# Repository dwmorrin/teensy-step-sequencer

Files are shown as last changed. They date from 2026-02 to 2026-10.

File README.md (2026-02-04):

# Teensy Step Sequencer

This project implements a hardware-based step sequencer using the Teensy 4.1 microcontroller. It utilizes the Teensy's onboard USB Host capabilities to accept input from standard USB keyboards, alongside a custom 32-switch diode matrix for tactile control.

## Gallery

### Version 1 first build
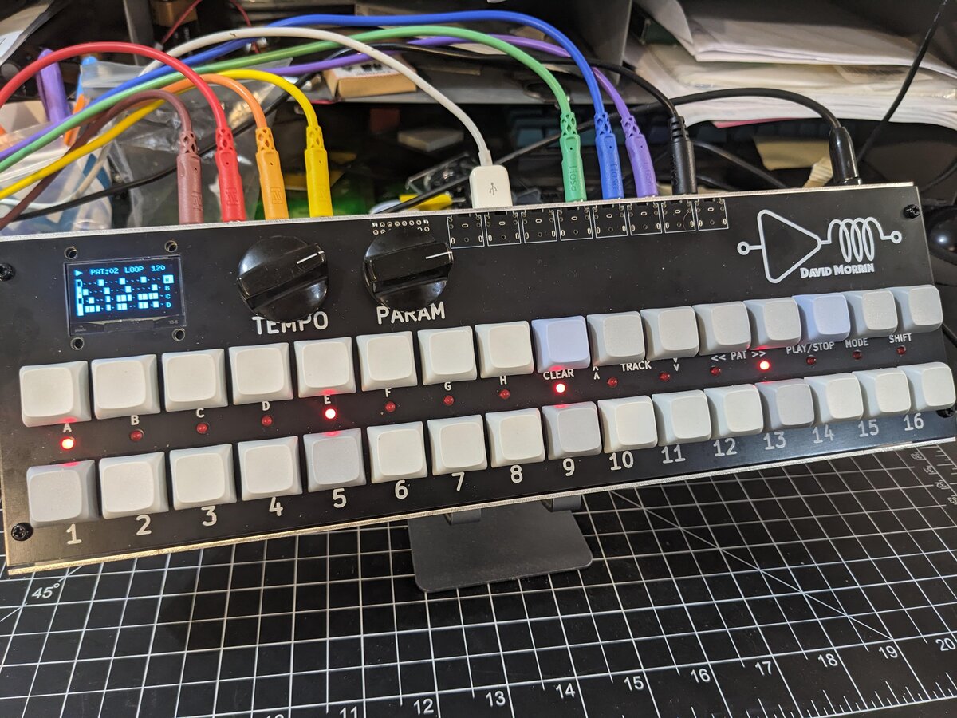
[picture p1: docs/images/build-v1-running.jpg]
Version 1 first build


### Prototype

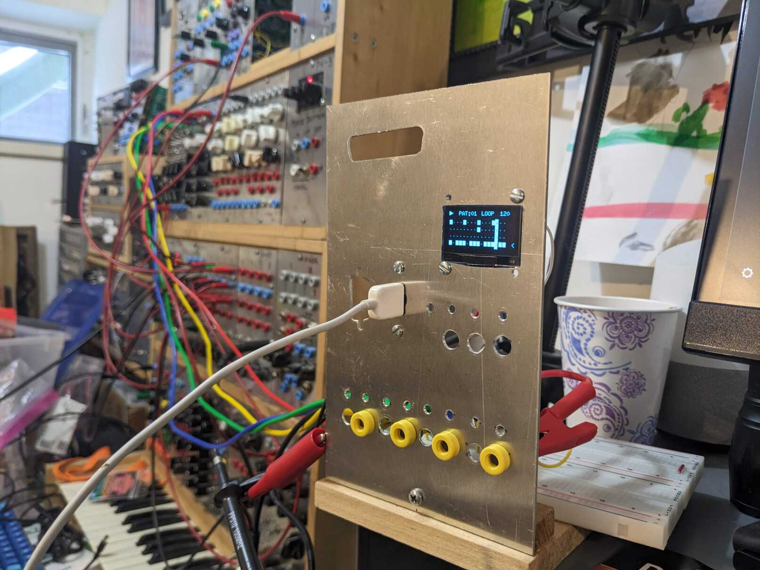
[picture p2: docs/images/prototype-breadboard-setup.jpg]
Breadboard Setup


### Hardware Renders

| Main Board | Switchplate |
| :---: | :---: |
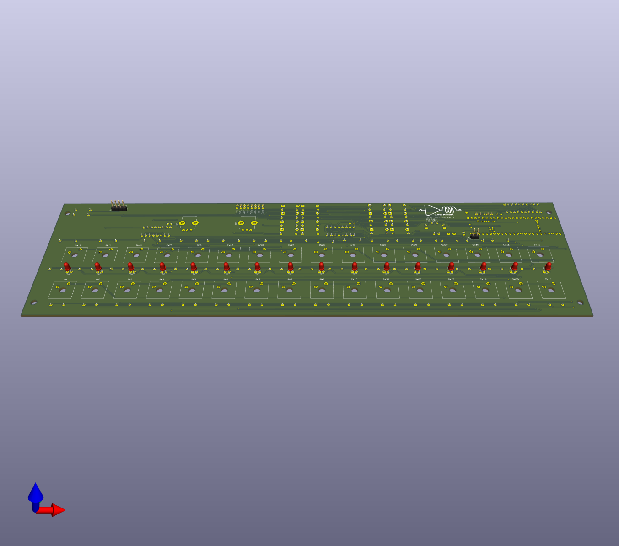
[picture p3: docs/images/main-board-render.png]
Main Board Render
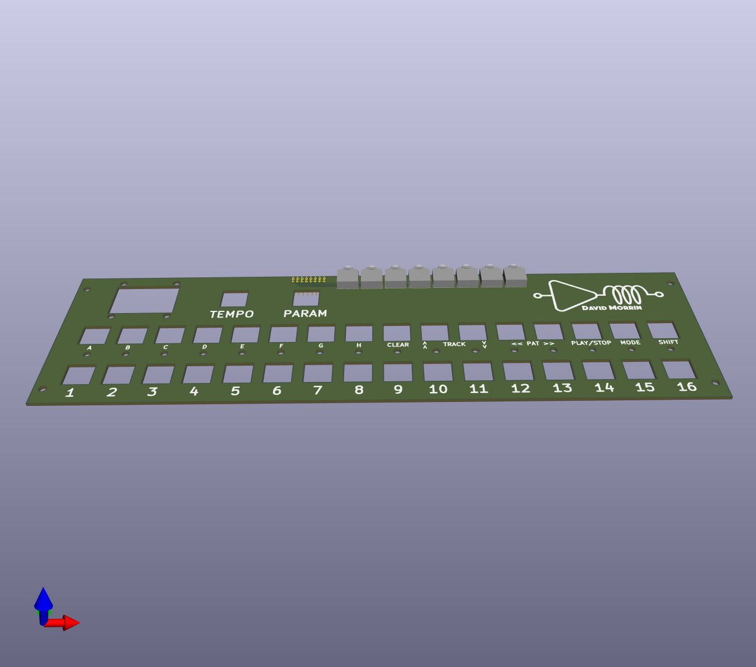
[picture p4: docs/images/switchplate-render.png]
Switchplate Render
|  |  |

## System Overview

The application is designed as a standalone, embedded instrument. It functions as an **8-track** step sequencer with support for **96 PPQN high-resolution timing**, pattern chaining (Song Mode), **per-track swing**, real-time performance triggers, and visual feedback via an I2C OLED display with scrolling track views.

### Hardware Dependencies

- **Microcontroller:** Teensy 4.1 (Selected for native USB Host and RAM capacity).
- **Display:** - 1.3" SH1106 OLED (I2C) for the graphical interface.
  - 16x LEDs driven by 74HC595 Shift Registers for step visualization.
- **Input:** - Standard USB HID Keyboard (via USB Host).
  - 4x8 Diode Matrix Keyboard (32 switches).
  - 2x Analog Potentiometers (Tempo and Parameter control).
- **Output:** **8x** 5V Logic Triggers (GPIO).

## Software Architecture

The codebase adopts a modular architecture separating data, presentation, and hardware control. The source code located in `src/` is organized into the following domains:

- **Model** (`src/Model/`)
  This directory contains the core logic and data structures. It serves as the single source of truth for the application, managing the Pattern Pool, the Playlist (Song Mode), Swing parameters, and the Undo buffer. The Model is decoupled from hardware; it does not know if it is being driven by a clock or edited by a keyboard.

- **View** (`src/View/`)
  This directory handles all visual output.
  - `DisplayManager`: Observes the Model and renders the interface (Grid, Transport, Headers) to the OLED. It handles **viewport scrolling** to display 8 tracks on a 4-track height screen.
  - `StepLeds`: Manages the 16-step LED array via SPI shift registers.
    The view layer includes internal throttling logic to maintain a consistent frame rate without blocking the audio/timing threads.

- **Controller** (`src/Controller/`)
  This directory manages user input and state routing. The `UIManager` aggregates inputs from multiple hardware sources:
  - **USB Keyboard:** Handled via the Teensy USBHost_t36 library.
  - **Matrix:** Handled by `KeyMatrix`, a custom driver for scanning the 4x8 diode array.
  - **Analog:** Handled by `AnalogInput`, which provides hysteresis and signal smoothing for potentiometers.

  Inputs are translated into abstract `InputCommands` (e.g., `CMD_TRANSPORT_TOGGLE`), decoupling the physical control method from the internal application logic.

- **Engine** (`src/Engine/`)
  This directory handles real-time operations.
  - `ClockEngine`: A **96 PPQN** (Pulses Per Quarter Note) interrupt-driven engine. It calculates micro-timing for **Swing** and groove effects, offering 24 "ticks" per 16th-note step.
  - `OutputDriver`: Abstraction layer for the physical hardware. It converts track bitmasks into GPIO signals using high-precision interrupt timers.

- **Configuration** (`src/Config.h`)
  A global header file defining build-time constraints, including track count, pattern limits, pin mappings, and signal polarity.

## Expansion Guidelines

The system is designed to be extensible. Developers looking to expand functionality should consider the following architectural patterns:

### Persistence (SD Card Storage)

Current pattern data is stored in volatile RAM and is lost upon power cycle. The Teensy 4.1 includes a native micro-SD card slot. Future development should implement a `PersistenceManager` class. This component should:

1.  Serialize the `SequencerModel` data structures (Pattern Pool and Playlist) into a binary or JSON format.
2.  Write to the SD card using the standard Arduino SD library.
3.  Interface with the `UIManager` to allow loading and saving of projects.

## Timing Calculation

The system timing is based on a standard 4/4 time signature where a "beat" represents a quarter note. 

The engine runs at **96 PPQN** resolution. The interval $T$ (milliseconds per tick) is calculated as:

$$T = \frac{60,000}{BPM \times 96}$$

For a standard trigger pulse width of 15ms, the system manages overlapping triggers via a pulse-counter in the interrupt service routine.

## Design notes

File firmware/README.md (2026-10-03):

# 8-Track Performance Sequencer (Firmware v1.0.0)

A interrupt-driven step sequencer for Teensy 4.1.

## Features

- **8-Track Polyphony:** 8 independent trigger outputs.
- **96 PPQN Timing Engine:** High-resolution jitter-free timing based on hardware interrupts.
- **Groove Engine:** Per-track Swing (0-100%) with visual grid feedback.
- **Performance Quantization:** Launch patterns synced to 1 Bar, 1/4 Note, 1/8 Note, or Instant.
- **Song Mode:** Chained pattern playback with insert/delete editing.
- **Persistent Storage:** Save and load entire sequencer state (BPM, Patterns, Playlist) to the Teensy's built-in microSD card in JSON format.
- **Scrolling Interface:** 128x64 OLED UI with auto-scrolling track view and "Gutter" labels.

## Controls

### Global & Transport

| Button | Function | Shift Function |
| :--- | :--- | :--- |
| **PLAY** | Play / Stop | **Quantize Menu** (Set Launch Mode) |
| **MODE** | Toggle Song / Loop Mode | Toggle Edit / Perform Mode |
| **BPM**  | Enter BPM Menu | - |
| **UNDO** | - | **Undo Last Action** (Shift + H) |

### Navigation & Selection

| Button | Function | Shift Function |
| :--- | :--- | :--- |
| **A** | Select Track 1 | **Save State to SD** |
| **B** | Select Track 2 | **Load State from SD** |
| **C - H** | Select Active Track (3 - 8) | - |
| **< / >** | Previous / Next Pattern | - |
| **^ / v** | Previous / Next Track (Scrolls View) | - |

### Editing (Step Edit Mode)

| Control | Action |
| :--- | :--- |
| **Steps 1-16** | Toggle Step ON/OFF |
| **Param Pot** | _Unused in Loop Mode_ |
| **Shift + Param** | **Set Swing %** for Active Track |

### Performance (Perform Mode)

| Control | Action |
| :--- | :--- |
| **Steps 1-8** | Manual Trigger / Finger Drumming |

### Song Mode (Playlist)

| Control | Action | Shift Action |
| :--- | :--- | :--- |
| **Param Pot**  | Select Pattern for current slot | - |
| **< / >** | Move Cursor / Scroll Playlist | Insert Slot Before/After |
| **Clear** | Delete Current Slot | - |
| **Steps 1-16** | Quick Select Pattern Bank | Select Bank 1-4 |

## Architecture

- **Model:** `SequencerModel` holds the state (Patterns, Playlist, Swing). It is decoupled from the engine.
- **Storage:** `StorageManager` serializes the model to/from JSON and interfaces with the built-in SD card.
- **Engine:** `ClockEngine` runs at **2kHz** (0.5ms interval), accumulating time to drive a **96 PPQN** virtual clock. It handles swing delays and trigger pulse widths.
- **Controller:** `UIManager` maps a 4x8 Matrix and Analog Inputs to Commands.
- **View:** `DisplayManager` renders the state to an SSD1306 OLED, handling scrolling offsets and overlays.

## Hardware Map

- **MicroSD:** Teensy 4.1 Built-in SDIO
- **Outputs 1-8:** Pins 25-32
- **Tempo Pot:** Pin 14
- **Param Pot:** Pin 15
- **Matrix Rows:** 36, 34, 38, 40 (Active Low)
- **Matrix Cols:** 20, 17, 16, 41, 39, 37, 35, 33 (Input Pullup)

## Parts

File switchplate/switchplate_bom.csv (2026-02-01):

Reference | Qty | Value | DNP | Exclude from BOM | Exclude from Board | Footprint | Datasheet | MPN
J1,J2,J3,J4,J5,J6,J7,J8 | 8 | AudioJack2 |  |  |  | Connector_Audio:Jack_3.5mm_CUI_SJ1-3523N_Horizontal | https://www.mouser.com/datasheet/3/6118/1/sj1_352xn.pdf | SJ1-3523N
J9 | 1 | Conn_02x08_Odd_Even |  |  |  | Connector_PinHeader_2.54mm:PinHeader_2x08_P2.54mm_Vertical | https://suddendocs.samtec.com/productspecs/tsw-sxx.pdf | TSW-108-14-T-D

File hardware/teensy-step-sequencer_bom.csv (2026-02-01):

Reference | Qty | Value | DNP | Exclude from BOM | Exclude from Board | Footprint | Datasheet
C1 | 1 | 100u |  |  |  | Capacitor_THT:CP_Radial_D5.0mm_P2.50mm | ~
C2,C3,C4 | 3 | 100n |  |  |  | Capacitor_THT:C_Disc_D5.0mm_W2.5mm_P2.50mm | ~
D1,D2,D3,D4,D5,D6,D7,D8,D9,D10,D11,D12,D13,D14,D15,D16,D19,D20 | 18 | LED |  |  |  | LED_THT:LED_D3.0mm | ~
D17,D18,D21,D22,D23,D24,D25,D26,D27,D28,D29,D30,D31,D32,D33,D34 | 16 | 1N5817 |  |  |  | Diode_THT:D_DO-15_P10.16mm_Horizontal | http://www.vishay.com/docs/88525/1n5817.pdf
D35,D36,D37,D38,D39,D40,D41,D42,D43,D44,D45,D46,D47,D48,D49,D50,D51,D52,D53,D54,D55,D56,D57,D58,D59,D60,D61,D62,D63,D64,D65,D66 | 32 | 1N4148 |  |  |  | Diode_THT:D_DO-35_SOD27_P7.62mm_Horizontal | ~
J1 | 1 | SH1106 Screen |  |  |  | Connector_PinHeader_2.54mm:PinHeader_1x04_P2.54mm_Vertical | ~
J2 | 1 | Output |  |  |  | Connector_PinHeader_2.54mm:PinHeader_2x08_P2.54mm_Vertical | ~
J3 | 1 | USB_HOST |  |  |  | Connector_PinHeader_2.54mm:PinHeader_1x05_P2.54mm_Vertical | ~
J4 | 1 | EXT_PWR |  |  |  | Connector_PinHeader_2.54mm:PinHeader_1x02_P2.54mm_Vertical | ~
R1,R2 | 2 | 4k7 |  |  |  | Resistor_THT:R_Axial_DIN0207_L6.3mm_D2.5mm_P10.16mm_Horizontal | ~
R3,R4,R5,R6,R7,R8,R9,R10,R11,R12,R13,R14,R15,R16,R17,R18,R20,R22,R23,R25,R26,R29,R30,R31,R32 | 25 | 330 |  |  |  | Resistor_THT:R_Axial_DIN0207_L6.3mm_D2.5mm_P10.16mm_Horizontal | ~
R19,R21,R24,R27,R28,R33,R34,R35,R36 | 9 | 1k |  |  |  | Resistor_THT:R_Axial_DIN0207_L6.3mm_D2.5mm_P10.16mm_Horizontal | ~
RV1,RV2 | 2 | 100k |  |  |  | Potentiometer_THT:Potentiometer_Bourns_PTV09A-1_Single_Vertical | ~
SW1,SW2,SW3,SW4,SW5,SW6,SW7,SW8,SW9,SW10,SW11,SW12,SW13,SW14,SW15,SW16,SW17,SW18,SW19,SW20,SW21,SW22,SW23,SW24,SW25,SW26,SW27,SW28,SW29,SW30,SW31,SW32 | 32 | CherryMX |  |  |  | CherryMX:CherryMX_1.00u
TP1 | 1 | 5V |  |  |  | TestPoint:TestPoint_Keystone_5000-5004_Miniature | ~
TP2 | 1 | 3V3 |  |  |  | TestPoint:TestPoint_Keystone_5000-5004_Miniature | ~
TP3 | 1 | GND |  |  |  | TestPoint:TestPoint_Keystone_5000-5004_Miniature | ~
U1 | 1 | Teensy4.1 |  |  |  | teensy:Teensy41
U2,U3 | 2 | 74HC595 |  |  |  | Package_DIP:DIP-16_W7.62mm | http://www.ti.com/lit/ds/symlink/sn74hc595.pdf
U4 | 1 | 74HCT245 |  |  |  | Package_DIP:DIP-20_W7.62mm | http://www.ti.com/lit/gpn/sn74HC245

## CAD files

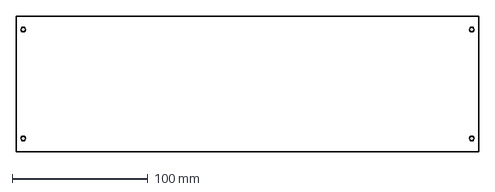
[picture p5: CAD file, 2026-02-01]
mechanical/board_edge.dxf
340.0 x 100.0 mm

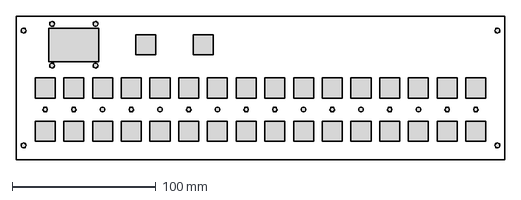
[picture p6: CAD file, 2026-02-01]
mechanical/component_guides.dxf
340.0 x 100.0 mm

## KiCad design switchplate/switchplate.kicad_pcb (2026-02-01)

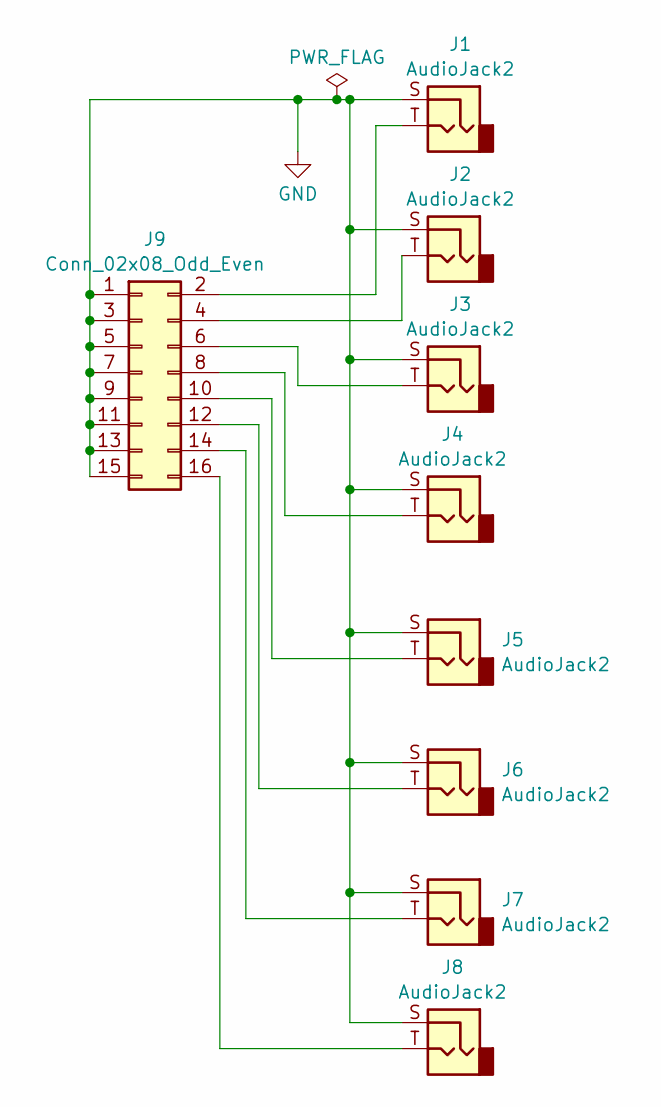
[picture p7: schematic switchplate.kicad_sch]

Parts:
J1, J2, J3, J4, J5, J6, J7, J8: AudioJack2; Jack_3.5mm_CUI_SJ1-3523N_Horizontal; MPN SJ1-3523N
J9: Conn_02x08_Odd_Even; PinHeader_2x08_P2.54mm_Vertical; MPN TSW-108-14-T-D

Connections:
GND: J1.S, J2.S, J3.S, J4.S, J5.S, J6.S, J7.S, J8.S, J9.1, J9.3, J9.5, J9.7, J9.9, J9.11, J9.13, J9.15
unnamed: J1.T, J9.2
unnamed: J2.T, J9.4
unnamed: J3.T, J9.6
unnamed: J4.T, J9.8
unnamed: J5.T, J9.10
unnamed: J6.T, J9.12
unnamed: J7.T, J9.14
unnamed: J8.T, J9.16

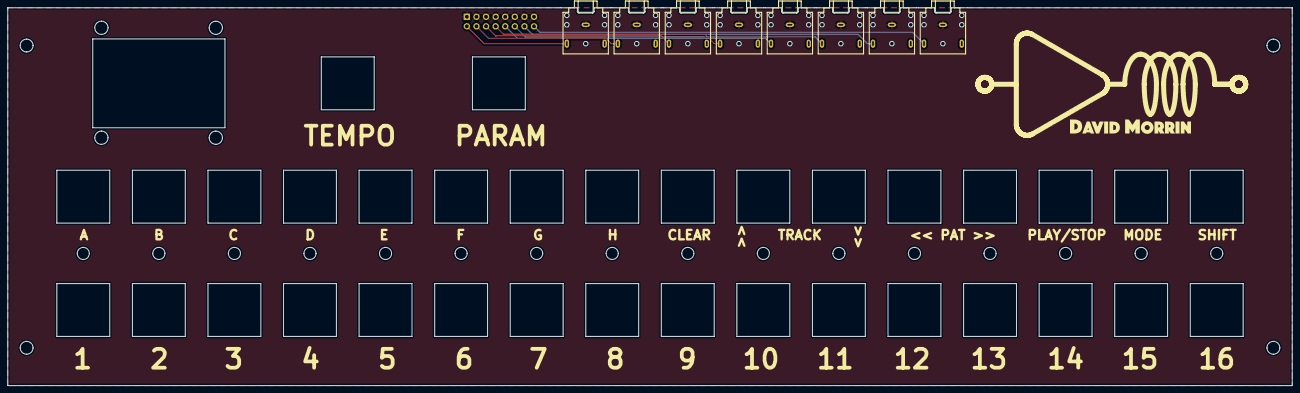
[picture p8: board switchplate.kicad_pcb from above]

Board: 2 copper layers, 340.0 x 100.0 mm, 9 parts (1 on the bottom side), 9 nets.

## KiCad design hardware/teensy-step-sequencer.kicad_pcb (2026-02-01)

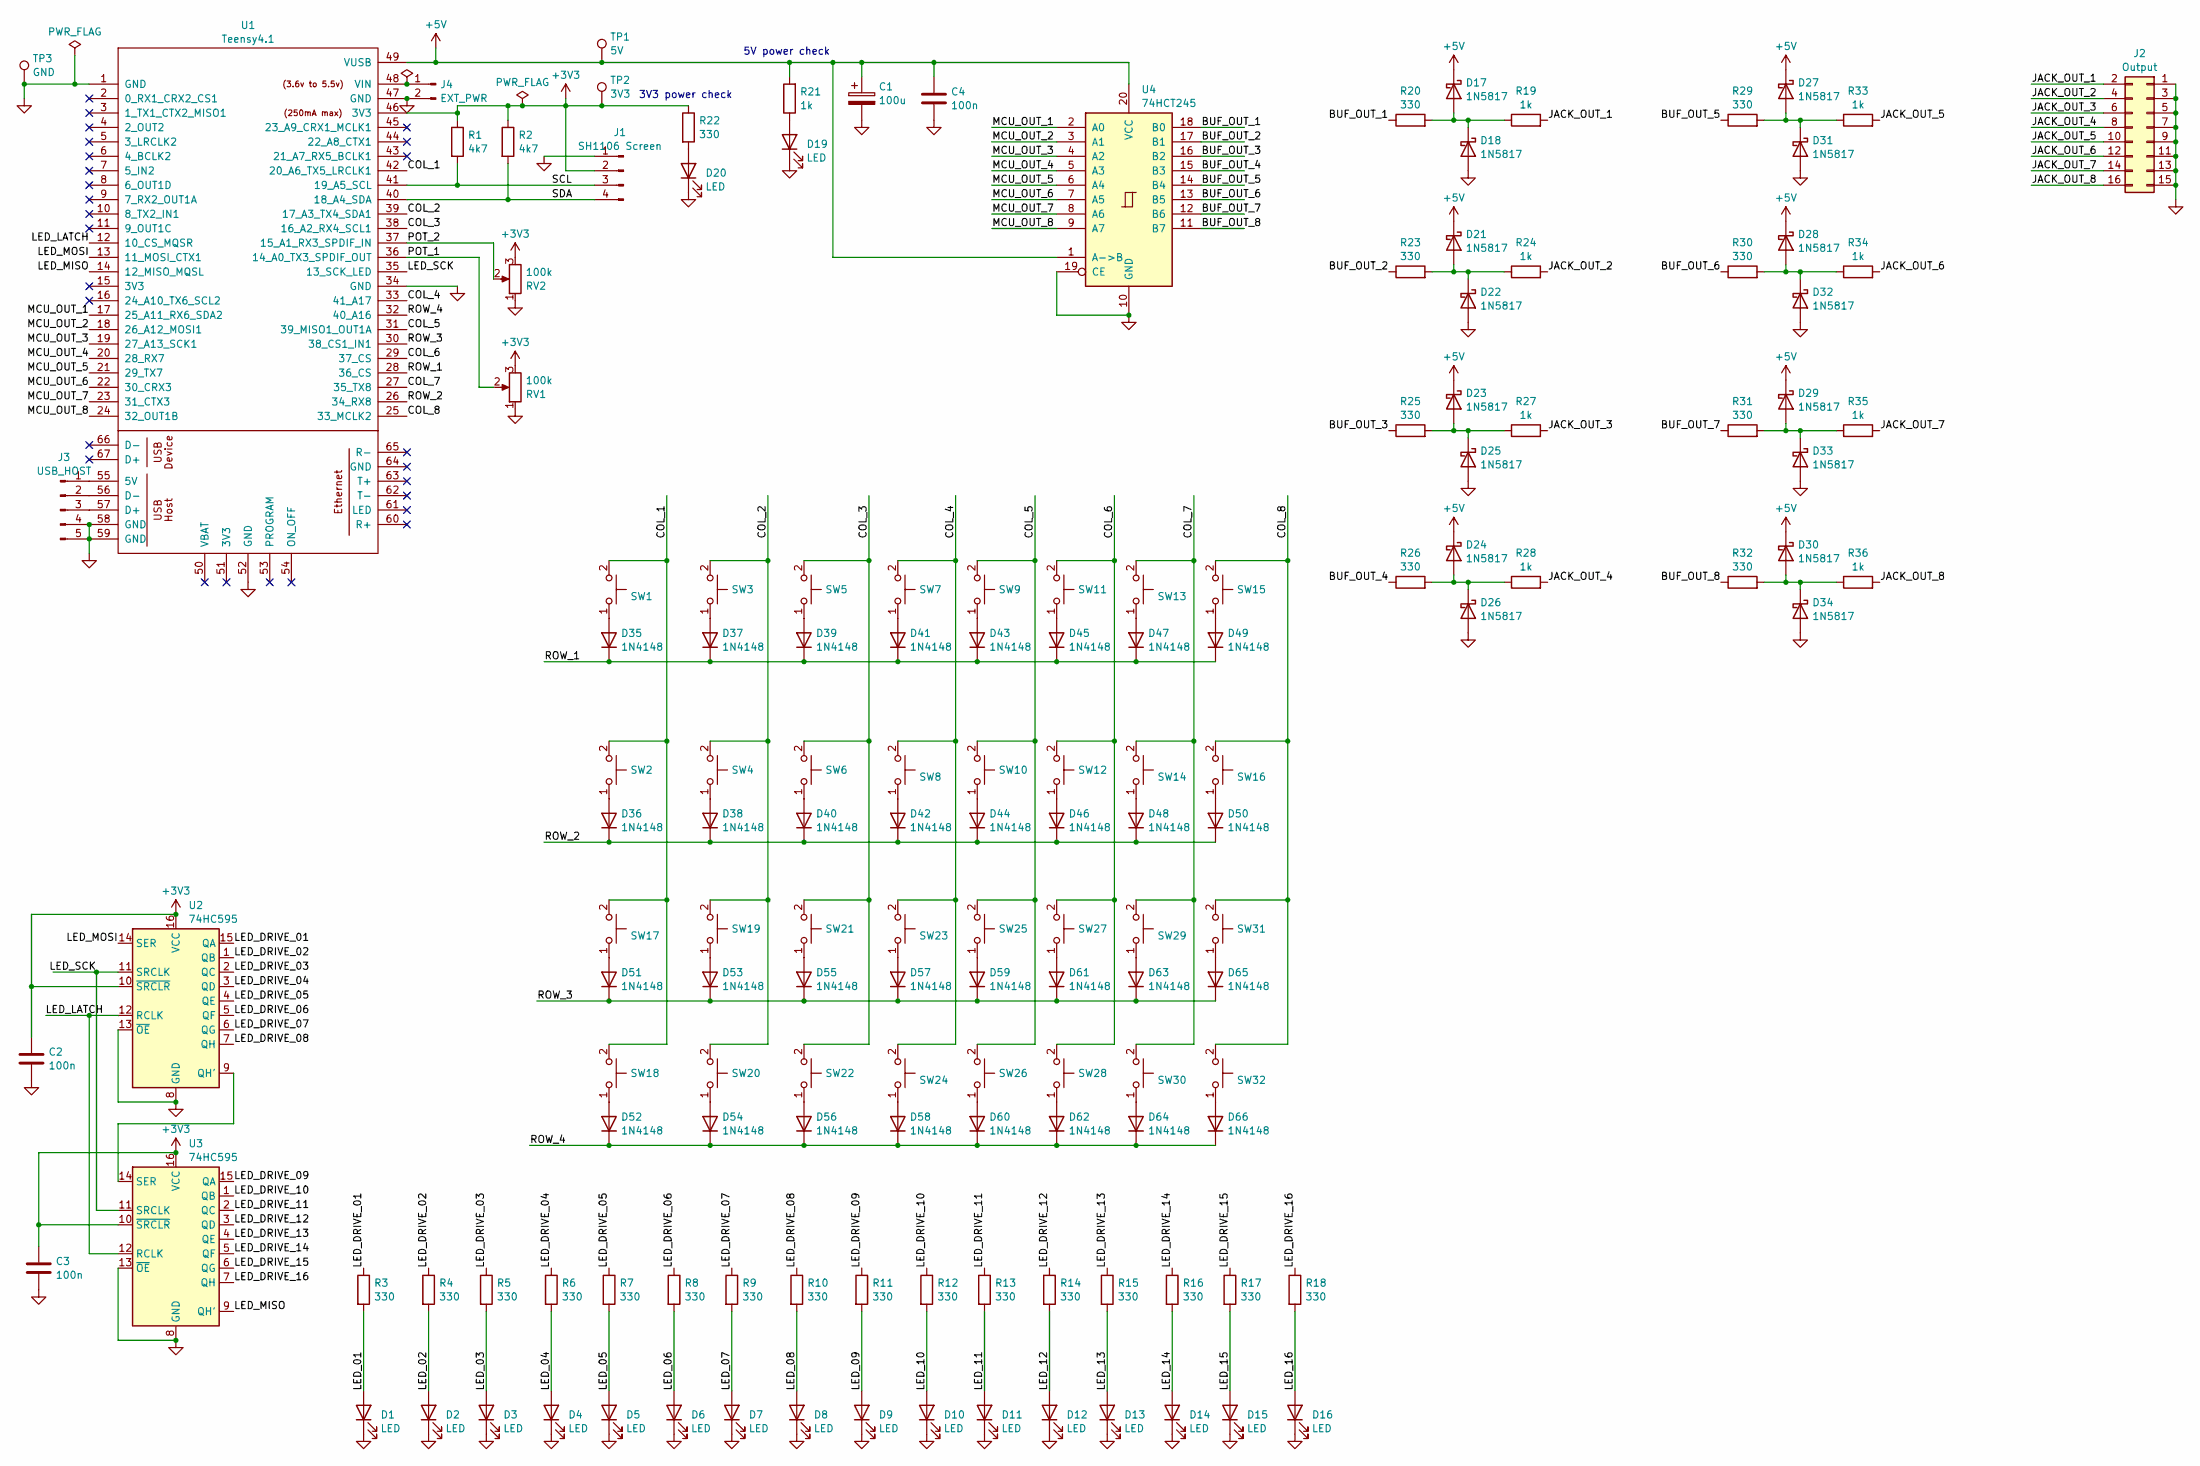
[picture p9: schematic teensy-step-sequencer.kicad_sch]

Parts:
C1: 100u; CP_Radial_D5.0mm_P2.50mm
C2, C3, C4: 100n; C_Disc_D5.0mm_W2.5mm_P2.50mm
D1, D2, D3, D4, D5, D6, D7, D8, D9, D10, D11, D12, D13, D14, D15, D16, D19, D20: LED; LED_D3.0mm
D17, D18, D21, D22, D23, D24, D25, D26, D27, D28, D29, D30, D31, D32, D33, D34: 1N5817; D_DO-15_P10.16mm_Horizontal
D35, D36, D37, D38, D39, D40, D41, D42, D43, D44, D45, D46, D47, D48, D49, D50, D51, D52, D53, D54, D55, D56, D57, D58, D59, D60, D61, D62, D63, D64, D65, D66: 1N4148; D_DO-35_SOD27_P7.62mm_Horizontal
J1: SH1106 Screen; PinHeader_1x04_P2.54mm_Vertical
J2: Output; PinHeader_2x08_P2.54mm_Vertical
J3: USB_HOST; PinHeader_1x05_P2.54mm_Vertical
J4: EXT_PWR; PinHeader_1x02_P2.54mm_Vertical
R1, R2: 4k7; R_Axial_DIN0207_L6.3mm_D2.5mm_P10.16mm_Horizontal
R3, R4, R5, R6, R7, R8, R9, R10, R11, R12, R13, R14, R15, R16, R17, R18, R20, R22, R23, R25, R26, R29, R30, R31, R32: 330; R_Axial_DIN0207_L6.3mm_D2.5mm_P10.16mm_Horizontal
R19, R21, R24, R27, R28, R33, R34, R35, R36: 1k; R_Axial_DIN0207_L6.3mm_D2.5mm_P10.16mm_Horizontal
RV1, RV2: 100k; Potentiometer_Bourns_PTV09A-1_Single_Vertical
SW1, SW2, SW3, SW4, SW5, SW6, SW7, SW8, SW9, SW10, SW11, SW12, SW13, SW14, SW15, SW16, SW17, SW18, SW19, SW20, SW21, SW22, SW23, SW24, SW25, SW26, SW27, SW28, SW29, SW30, SW31, SW32: CherryMX; CherryMX_1.00u
TP1: 5V; TestPoint_Keystone_5000-5004_Miniature
TP2: 3V3; TestPoint_Keystone_5000-5004_Miniature
TP3: GND; TestPoint_Keystone_5000-5004_Miniature
U1: Teensy4.1; Teensy41
U2, U3: 74HC595; DIP-16_W7.62mm
U4: 74HCT245; DIP-20_W7.62mm

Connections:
+3V3: C2.1, C3.1, J1.2, R1.1, R2.1, R22.1, RV1.3, RV2.3, TP2.1, U1.46 (3V3), U2.10 (~SRCLR), U2.16 (VCC), U3.10 (~SRCLR), U3.16 (VCC)
+5V: C1.1, C4.1, D17.1 (K), D21.1 (K), D23.1 (K), D24.1 (K), D27.1 (K), D28.1 (K), D29.1 (K), D30.1 (K), R21.2, TP1.1, U1.49 (VUSB), U4.1 (A->B), U4.20 (VCC)
/BUF_OUT_1: R20.1, U4.18 (B0)
/BUF_OUT_2: R23.1, U4.17 (B1)
/BUF_OUT_3: R25.1, U4.16 (B2)
/BUF_OUT_4: R26.1, U4.15 (B3)
/BUF_OUT_5: R29.1, U4.14 (B4)
/BUF_OUT_6: R30.1, U4.13 (B5)
/BUF_OUT_7: R31.1, U4.12 (B6)
/BUF_OUT_8: R32.1, U4.11 (B7)
/COL_1: SW1.2, SW2.2, SW17.2, SW18.2, U1.42 (20_A6_TX5_LRCLK1)
/COL_2: SW3.2, SW4.2, SW19.2, SW20.2, U1.39 (17_A3_TX4_SDA1)
/COL_3: SW5.2, SW6.2, SW21.2, SW22.2, U1.38 (16_A2_RX4_SCL1)
/COL_4: SW7.2, SW8.2, SW23.2, SW24.2, U1.33 (41_A17)
/COL_5: SW9.2, SW10.2, SW25.2, SW26.2, U1.31 (39_MISO1_OUT1A)
/COL_6: SW11.2, SW12.2, SW27.2, SW28.2, U1.29 (37_CS)
/COL_7: SW13.2, SW14.2, SW29.2, SW30.2, U1.27 (35_TX8)
/COL_8: SW15.2, SW16.2, SW31.2, SW32.2, U1.25 (33_MCLK2)
/JACK_OUT_1: J2.2, R19.2
/JACK_OUT_2: J2.4, R24.2
/JACK_OUT_3: J2.6, R27.2
/JACK_OUT_4: J2.8, R28.2
/JACK_OUT_5: J2.10, R33.2
/JACK_OUT_6: J2.12, R34.2
/JACK_OUT_7: J2.14, R35.2
/JACK_OUT_8: J2.16, R36.2
/LED_01: D1.2 (A), R3.2
/LED_02: D2.2 (A), R4.2
/LED_03: D3.2 (A), R5.2
/LED_04: D4.2 (A), R6.2
/LED_05: D5.2 (A), R7.2
/LED_06: D6.2 (A), R8.2
/LED_07: D7.2 (A), R9.2
/LED_08: D8.2 (A), R10.2
/LED_09: D9.2 (A), R11.2
/LED_10: D10.2 (A), R12.2
/LED_11: D11.2 (A), R13.2
/LED_12: D12.2 (A), R14.2
/LED_13: D13.2 (A), R15.2
/LED_14: D14.2 (A), R16.2
/LED_15: D15.2 (A), R17.2
/LED_16: D16.2 (A), R18.2
/LED_DRIVE_01: R3.1, U2.15 (QA)
/LED_DRIVE_02: R4.1, U2.1 (QB)
/LED_DRIVE_03: R5.1, U2.2 (QC)
/LED_DRIVE_04: R6.1, U2.3 (QD)
/LED_DRIVE_05: R7.1, U2.4 (QE)
/LED_DRIVE_06: R8.1, U2.5 (QF)
/LED_DRIVE_07: R9.1, U2.6 (QG)
/LED_DRIVE_08: R10.1, U2.7 (QH)
/LED_DRIVE_09: R11.1, U3.15 (QA)
/LED_DRIVE_10: R12.1, U3.1 (QB)
/LED_DRIVE_11: R13.1, U3.2 (QC)
/LED_DRIVE_12: R14.1, U3.3 (QD)
/LED_DRIVE_13: R15.1, U3.4 (QE)
/LED_DRIVE_14: R16.1, U3.5 (QF)
/LED_DRIVE_15: R17.1, U3.6 (QG)
/LED_DRIVE_16: R18.1, U3.7 (QH)
/LED_LATCH: U1.12 (10_CS_MQSR), U2.12 (RCLK), U3.12 (RCLK)
/LED_MISO: U1.14 (12_MISO_MQSL), U3.9 (QH')
/LED_MOSI: U1.13 (11_MOSI_CTX1), U2.14 (SER)
/LED_SCK: U1.35 (13_SCK_LED), U2.11 (SRCLK), U3.11 (SRCLK)
/MCU_OUT_1: U1.17 (25_A11_RX6_SDA2), U4.2 (A0)
/MCU_OUT_2: U1.18 (26_A12_MOSI1), U4.3 (A1)
/MCU_OUT_3: U1.19 (27_A13_SCK1), U4.4 (A2)
/MCU_OUT_4: U1.20 (28_RX7), U4.5 (A3)
/MCU_OUT_5: U1.21 (29_TX7), U4.6 (A4)
/MCU_OUT_6: U1.22 (30_CRX3), U4.7 (A5)
/MCU_OUT_7: U1.23 (31_CTX3), U4.8 (A6)
/MCU_OUT_8: U1.24 (32_OUT1B), U4.9 (A7)
/POT_1: RV1.2, U1.36 (14_A0_TX3_SPDIF_OUT)
/POT_2: RV2.2, U1.37 (15_A1_RX3_SPDIF_IN)
/ROW_1: D35.1 (K), D37.1 (K), D39.1 (K), D41.1 (K), D43.1 (K), D45.1 (K), D47.1 (K), D49.1 (K), U1.28 (36_CS)
/ROW_2: D36.1 (K), D38.1 (K), D40.1 (K), D42.1 (K), D44.1 (K), D46.1 (K), D48.1 (K), D50.1 (K), U1.26 (34_RX8)
/ROW_3: D51.1 (K), D53.1 (K), D55.1 (K), D57.1 (K), D59.1 (K), D61.1 (K), D63.1 (K), D65.1 (K), U1.30 (38_CS1_IN1)
/ROW_4: D52.1 (K), D54.1 (K), D56.1 (K), D58.1 (K), D60.1 (K), D62.1 (K), D64.1 (K), D66.1 (K), U1.32 (40_A16)
/SCL: J1.3, R1.2, U1.41 (19_A5_SCL)
/SDA: J1.4, R2.2, U1.40 (18_A4_SDA)
GND: C1.2, C2.2, C3.2, C4.2, D1.1 (K), D2.1 (K), D3.1 (K), D4.1 (K), D5.1 (K), D6.1 (K), D7.1 (K), D8.1 (K), D9.1 (K), D10.1 (K), D11.1 (K), D12.1 (K), D13.1 (K), D14.1 (K), D15.1 (K), D16.1 (K), D18.2 (A), D19.1 (K), D20.1 (K), D22.2 (A), D25.2 (A), D26.2 (A), D31.2 (A), D32.2 (A), D33.2 (A), D34.2 (A), J1.1, J2.1, J2.3, J2.5, J2.7, J2.9, J2.11, J2.13, J2.15, J3.4, J3.5, J4.2, RV1.1, RV2.1, TP3.1, U1.1 (GND), U1.34 (GND), U1.47 (GND), U1.52 (GND), U1.58 (GND), U1.59 (GND), U2.8 (GND), U2.13 (~OE), U3.8 (GND), U3.13 (~OE), U4.10 (GND), U4.19 (CE)
unnamed: D17.2 (A), D18.1 (K), R19.1, R20.2
unnamed: D19.2 (A), R21.1
unnamed: D20.2 (A), R22.2
unnamed: D21.2 (A), D22.1 (K), R23.2, R24.1
unnamed: D23.2 (A), D25.1 (K), R25.2, R27.1
unnamed: D24.2 (A), D26.1 (K), R26.2, R28.1
unnamed: D27.2 (A), D31.1 (K), R29.2, R33.1
unnamed: D28.2 (A), D32.1 (K), R30.2, R34.1
unnamed: D29.2 (A), D33.1 (K), R31.2, R35.1
unnamed: D30.2 (A), D34.1 (K), R32.2, R36.1
unnamed: D35.2 (A), SW1.1
unnamed: D36.2 (A), SW2.1
unnamed: D37.2 (A), SW3.1
unnamed: D38.2 (A), SW4.1
unnamed: D39.2 (A), SW5.1
unnamed: D40.2 (A), SW6.1
unnamed: D41.2 (A), SW7.1
unnamed: D42.2 (A), SW8.1
unnamed: D43.2 (A), SW9.1
unnamed: D44.2 (A), SW10.1
unnamed: D45.2 (A), SW11.1
unnamed: D46.2 (A), SW12.1
unnamed: D47.2 (A), SW13.1
unnamed: D48.2 (A), SW14.1
unnamed: D49.2 (A), SW15.1
unnamed: D50.2 (A), SW16.1
unnamed: D51.2 (A), SW17.1
unnamed: D52.2 (A), SW18.1
unnamed: D53.2 (A), SW19.1
unnamed: D54.2 (A), SW20.1
unnamed: D55.2 (A), SW21.1
unnamed: D56.2 (A), SW22.1
unnamed: D57.2 (A), SW23.1
unnamed: D58.2 (A), SW24.1
unnamed: D59.2 (A), SW25.1
unnamed: D60.2 (A), SW26.1
unnamed: D61.2 (A), SW27.1
unnamed: D62.2 (A), SW28.1
unnamed: D63.2 (A), SW29.1
unnamed: D64.2 (A), SW30.1
unnamed: D65.2 (A), SW31.1
unnamed: D66.2 (A), SW32.1
unnamed: J3.1, U1.55 (5V)
unnamed: J3.2, U1.56 (D-)
unnamed: J3.3, U1.57 (D+)
unnamed: J4.1, U1.48 (VIN)
unnamed: U2.9 (QH'), U3.14 (SER)

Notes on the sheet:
5V power check
3V3 power check

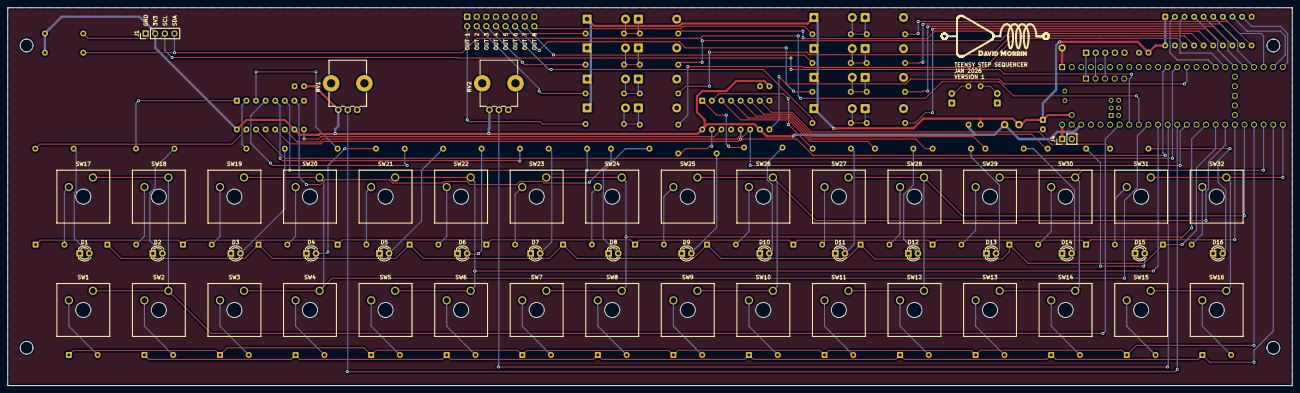
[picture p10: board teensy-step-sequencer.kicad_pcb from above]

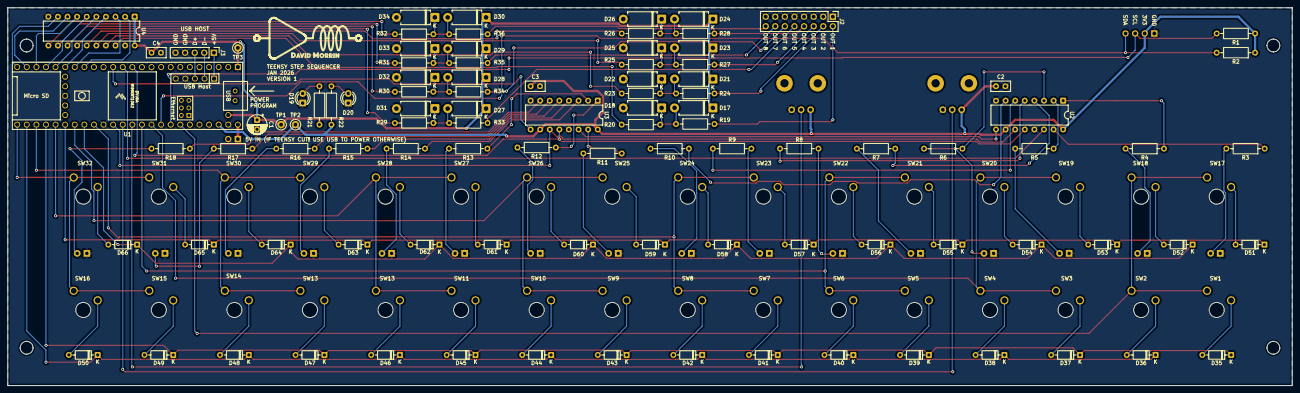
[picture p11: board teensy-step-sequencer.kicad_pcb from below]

Board: 2 copper layers, 340.0 x 100.0 mm, 151 parts (99 on the bottom side), 126 nets.

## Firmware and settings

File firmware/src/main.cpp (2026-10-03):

#include "Debug.h"
#include <Arduino.h>
#include <USBHost_t36.h>

// Core Components
#include "Model/SequencerModel.h"
#include "View/DisplayManager.h"
#include "Controller/UIManager.h"
#include "Engine/OutputDriver.h"
#include "Engine/ClockEngine.h"
#include "StorageManager/StorageManager.h"

// --- USB HOST SETUP ---
USBHost myusb;
USBHub hub1(myusb);
USBHub hub2(myusb); // Support for daisy-chained hubs
KeyboardController keyboard1(myusb);

// --- COMPONENT INSTANTIATION ---
// Hardware Definitions
const int PIN_SR_LATCH = 10;

SequencerModel model;
OutputDriver driver;
ClockEngine clockEngine(model, driver);
StorageManager storage;
UIManager ui(model, driver, clockEngine, storage);

// DisplayManager now receives the Latch Pin for the LEDs
DisplayManager display(model, ui, PIN_SR_LATCH);

// --- FORWARD DECLARATION ---
void globalKeyPress(int key);

// --- SETUP ---
void setup()
{
#ifdef DEBUG_MODE
  Serial.begin(9600);
#endif

  // 1. Init Subsystems
  driver.init();
  display.init(); // Inits OLED and LEDs
  ui.init();

  if (storage.init())
    storage.loadState(model);

  // 2. Init USB
  myusb.begin();
  keyboard1.attachPress(globalKeyPress);

  clockEngine.init();
}

// --- GLOBAL BRIDGE ---
// USBHost library requires a void function(int), not a class method.
void globalKeyPress(int key)
{
  ui.handleKeyPress(key);
}

// --- MAIN LOOP ---
void loop()
{
  // HARDWARE TASKS
  myusb.Task();

  // TIMING ENGINE
  clockEngine.update();

  // INTERFACE
  ui.processInput();
  display.update();

  // STORAGE
  if (ui.isSavePending())
    ui.executePendingSave();
  if (ui.isLoadPending())
    ui.executePendingLoad();
}

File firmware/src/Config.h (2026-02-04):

#pragma once

// --- SYSTEM LIMITS ---
#define NUM_TRACKS 8
#define NUM_STEPS 16
#define MAX_PATTERNS 64
#define MAX_SONG_LENGTH 128

// --- TIMING ---
#define PULSE_WIDTH_MS 15
#define DEFAULT_BPM 120

// --- HARDWARE MAPPING ---
const int OUTPUT_MAP[NUM_TRACKS] = {25, 26, 27, 28, 29, 30, 31, 32};

// --- INPUTS ---
const int PIN_POT_TEMPO = 14;
const int PIN_POT_PARAM = 15;

// KEY MATRIX PINS
// Rows (Active Low Output)
const int PIN_ROW_1 = 36;
const int PIN_ROW_2 = 34;
const int PIN_ROW_3 = 38;
const int PIN_ROW_4 = 40;

// Cols (Input Pullup)
const int PIN_COL_1 = 20;
const int PIN_COL_2 = 17;
const int PIN_COL_3 = 16;
const int PIN_COL_4 = 41;
const int PIN_COL_5 = 39;
const int PIN_COL_6 = 37;
const int PIN_COL_7 = 35;
const int PIN_COL_8 = 33;

// PCB REVISION NOTES
const bool POT_INVERT_POLARITY = true;

// --- OUTPUT POLARITY ---
#define TRIGGER_ON HIGH
#define TRIGGER_OFF LOW

// --- DISPLAY ---
#define TRACK_EDIT_STR "<"
#define TRACK_PERFORM_STR "*"

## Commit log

2026-01-24 fix: triggers run on timer
    [Config.h, main.cpp]
2026-01-24 feat: adds global debug switch
2026-01-25 fix: perform indicator
    TAB toggles between < and * track indicator with the latter meaning perform mode.
    Also compresses grid so the track indicator can be seen.
    [Config.h]
2026-01-25 feat: adds 'clear track' action
2026-02-01 refactor(hardware): migrate main board to clean directory structure and consolidate libraries
    [board_edge.dxf, component_guides.dxf, teensy-step-sequencer.kicad_pcb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]
2026-02-01 refactor(switchplate): migrate to monorepo structure and clean up libraries
    [switchplate.kicad_pcb, switchplate.kicad_sch, switchplate_bom.csv]
2026-02-01 feat(view): integrate LED step display and hardware diagnostics
    - Add StepLeds driver for 74HC595 shift registers with MISO loopback
    - Add MODE_HARDWARE_TEST to SequencerModel and ClockEngine
    - Implement high-speed visual chaser in ClockEngine (timing override)
    - Update DisplayManager to sync LEDs with model and report self-test results
    - Bind 't' key in UIManager to toggle diagnostic mode
    Closes #2
2026-02-01 feat(controller): integrate analog potentiometers for tempo and parameter control
    - Add AnalogInput helper class with hysteresis filtering
    - Define PIN_POT_TEMPO (14) and PIN_POT_PARAM (15) in Config.h
    - Implement 'Last Action Wins' logic for BPM control (Pot vs Keyboard)
    - Add POT_INVERT_POLARITY flag to correct V1 PCB layout error
    - Tune Tempo Pot threshold to 4 ADC units (~1 BPM resolution)
    - Set Output Logic to Active High for hardware probing
    Closes #3
    [Config.h]
2026-02-02 fix(config): update output pin mapping for V1 PCB
    - Update OUTPUT_MAP to use pins 25-28 instead of 2-5 to match the V1 hardware layout.
    [Config.h]
2026-02-02 feat(hardware): implement diode matrix keyboard driver
    - Add KeyMatrix class to scan 4x8 switch matrix with open-drain logic
    - Map physical matrix switches to InputCommands (Steps, Tracks A-D, Transport)
    - Integrate KeyMatrix polling into UIManager::processInput
    - Implement modal confirmation logic using Step buttons (1-4=YES, 13-16=NO)
    - Update DisplayManager to show hardware-specific guidance for Clear actions
    Closes #5
2026-02-02 docs(readme): update documentation to reflect hardware and architecture changes
    - Add hardware dependency details for Matrix, Analog Pots, and LED array
    - Update Software Architecture to describe InputCommand pattern and new Controller modules
    - Refine Timing Calculation section with mathematical notation
2026-02-04 fix(controller): implement event buffer for simultaneous keypresses
    - Add Ring Buffer to KeyMatrix to store multiple events per frame
    - Decouple hardware scan (update) from event processing (getNextEvent)
    - Update UIManager to consume all buffered events each loop
    - Remove unused _mapToSwitchID declaration
    Closes #6
    [KeyMatrix.cpp]
2026-02-04 fix(engine): move clock timing to hardware interrupt
    - Refactor ClockEngine to use IntervalTimer (1kHz ISR) for rock-solid timing
    - Eliminate tempo jitter caused by main loop/display latency
    - Simplify OutputDriver to be a stateless GPIO wrapper
    - Route manual UI triggers through ClockEngine to ensure correct pulse widths
    - Update initialization order in main.cpp to prevent startup glitches
    closes #10
    [main.cpp]
2026-02-04 feat(ux): implement enhanced song mode workflow
    - Implement Song Mode input layer with Bank Selection (Shift+1-4) and Direct Pattern Assignment
    - Add Playlist Editing commands: Insert Before/After (Shift+Arrows) and Delete Slot (Clear)
    - Update DisplayManager LED logic to show Playhead Chaser when playing and Pattern ID when stopped
    - Map Param Pot to fine-tune Pattern ID selection in Song Mode
2026-02-04 refactor(ux): swap Mode button behavior
    - Map MODE button to toggle Song/Loop Mode (CMD_SONG_MODE_TOGGLE)
    - Map SHIFT+MODE to toggle Edit/Perform Mode (CMD_MODE_TOGGLE)
    - Aligns hardware workflow with user preference for frequent Song Mode access
2026-02-04 feat(engine): implement 96 PPQN timing and per-track swing
    - Upgrade ClockEngine to 96 PPQN resolution (approx 2kHz ISR) for high-precision timing
    - Implement per-track, per-pattern Swing parameter (0-100%) in SequencerModel
    - Add tick-based trigger logic to delay off-beat steps based on swing amount
    - Map Shift+ParamPot in UIManager to control swing for the active track
    - Add visual feedback: transient value overlay and rhythmic grid displacement in DisplayManager
    Closes #1
2026-02-04 feat(hardware): expand to 8 tracks with scrolling UI
    - Increase NUM_TRACKS to 8 and update OUTPUT_MAP in Config.h
    - Update OutputDriver to initialize and trigger 8 pins
    - Remap Matrix inputs: Buttons A-H now select Tracks 1-8
    - Move UNDO command to SHIFT + H (formerly just H)
    - Implement scrolling grid in DisplayManager to view 8 tracks on a 4-track screen
    - Add visual track labels (A-H) in the right gutter for orientation
